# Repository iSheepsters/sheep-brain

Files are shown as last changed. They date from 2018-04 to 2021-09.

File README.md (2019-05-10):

# Config file

| Value | Description |
| --- | --- |
| sheepNum | the number for the sheep voices |
| stable sensor value | if non-zero, use as stable value
| privates enabled | if non-zero, private sensor is enabled
| R rated | if non-zero, R rated sounds enabled
| default volume | 0 - 63, 63 is maximum, 0 is silent, 50 is a typical loud volume
| min sound delay | minimum delay in seconds between sound clips (suggest 12)
| max sound delay | maximum delay in seconds between sound clips (suggest 25)
| time zone offset | difference from ET
| # time periods | the number of lines each containing the following fields 
| start duration volume | start is the starting o’clock in EST (0-23) for a volume reduction, duration is the number of hours, volume in that window

For example, the following config file
```
1
0
0
0
48
12
25
0
1
22 10 40
```

Specifies the following:
* Sheep 1
* privates not enabled
* R-rated sounds not enabled
* default volume of 48
* delay until next sound of 1/2 duration of previous clip plus 12-25 seconds
* no time zone offset (use EST)
* 1 time period offset
 * If time is between 10pm and 8am, use a volume of 40

# Libraries used

| Library | Version | Notes |
| --- | --- |  --- |
|Adafruit Sleepydog
|Wire
|TimeLib
|Adafruit\_GPS
|RH\_RF95
|Adafruit\_VS1053 | Custom | Modified to use SdFat
|SdFat
| Adafruit\_MPR121 | 

# Hardware

| Module | I2C  | Serial | SPI |  Notes |
| --- | --- | --- | --- | --- |
| [Feather M0/LoRa][1] | |  | 
| [Music Maker FeatherWing][2] |  | | yes | Both audio codec and SD card; SD select = 5
| [GPS Featherwing][3] | | yes | |
| [Capacitive Touch Sensor][4] | 0x5A | | | 
| [20W amplifier][5] | 0x4B | | | |
| Teensy 3.5 | 0x44 | | | 

[1]:	https://learn.adafruit.com/adafruit-feather-m0-radio-with-lora-radio-module/downloads
[2]:	https://learn.adafruit.com/adafruit-music-maker-featherwing/
[3]:	https://learn.adafruit.com/adafruit-ultimate-gps-featherwing
[4]:	https://learn.adafruit.com/adafruit-mpr121-12-key-capacitive-touch-sensor-breakout-tutorial
[5]:	https://learn.adafruit.com/adafruit-20w-stereo-audio-amplifier-class-d-max9744

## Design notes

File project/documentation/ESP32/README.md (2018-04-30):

GitHub:

Heltec Board: https://github.com/Heltec-Aaron-Lee/WiFi_Kit_series

Install (OSX): https://github.com/Heltec-Aaron-Lee/WiFi_Kit_series/blob/master/InstallGuide/mac.md

Product Page:
https://www.amazon.com/gp/product/B076MSLFC9/

Wiki:

Documentation:

ESP32: https://www.espressif.com/en/products/hardware/esp32/resources

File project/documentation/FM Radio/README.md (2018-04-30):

https://www.sparkfun.com/datasheets/Wireless/General/TEA5767.pdf
Best option? https://www.amazon.com/Gikfun-TEA5767-Stereo-Module-Arduino/dp/B00RECZ142
https://www.hackster.io/nickthegreek82/arduino-tea5767-fm-radio-receiver-543480

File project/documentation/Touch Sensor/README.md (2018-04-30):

# GitHub:

# Product Page:
https://www.adafruit.com/product/1982

# Wiki:

# Documentation:
Tutorial: https://learn.adafruit.com/adafruit-mpr121-12-key-capacitive-touch-sensor-breakout-tutorial
General intro to touch: https://learn.adafruit.com/adafruit-capacitive-touch-sensor-breakouts?embeds=allow

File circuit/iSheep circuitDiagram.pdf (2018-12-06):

Head LEDs | Left side LEDs | Right side LEDs

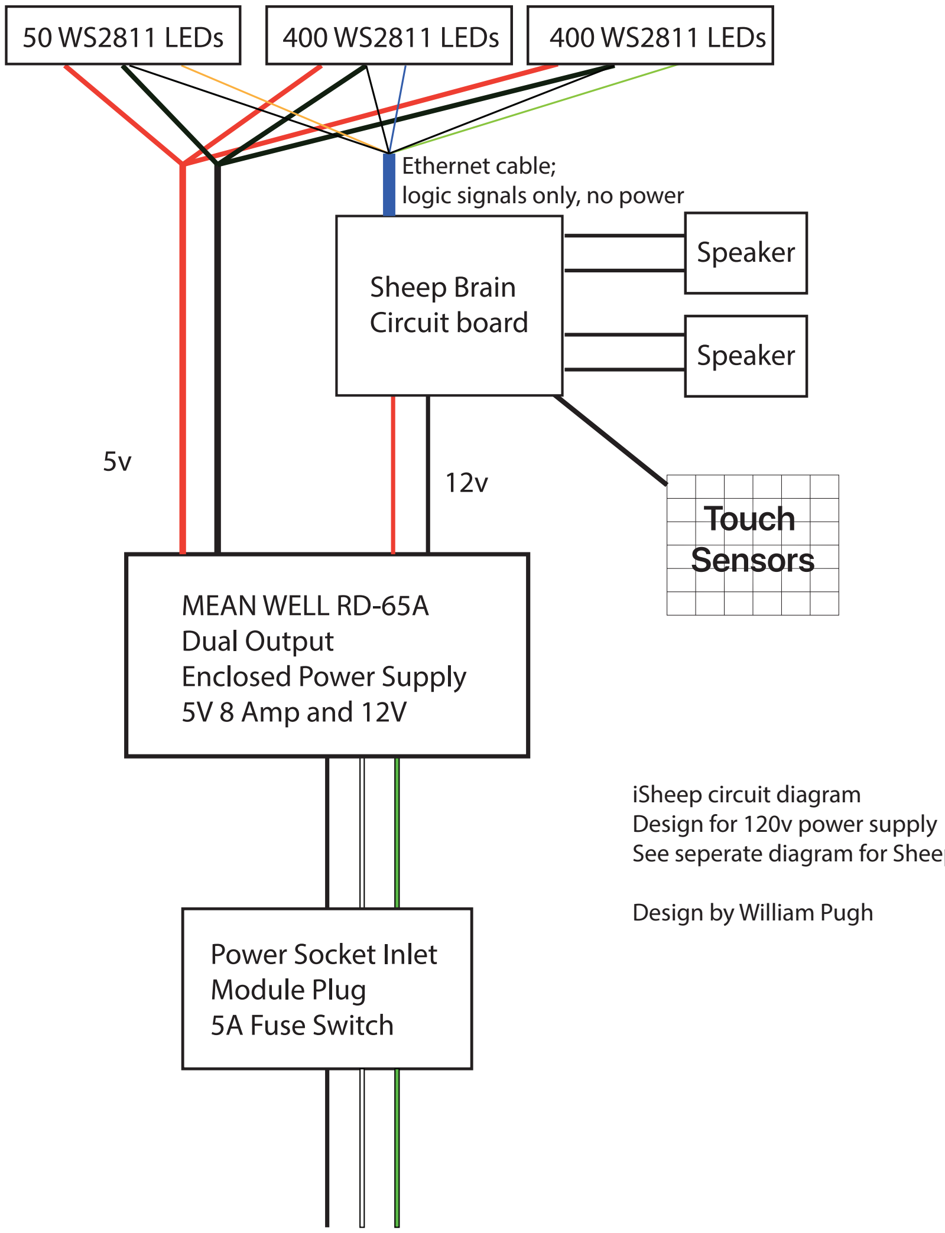
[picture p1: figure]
Power Socket Inlet Module Plug 5A Fuse Switch; MEAN WELL RD-65A Dual Output Enclosed Power Supply 5V 8 Amp and 12V; Sheep Brain Circuit board; Speaker; Touch Sensors; Ethernet cable; logic signals only, no power; iSheep circuit diagram Design for 120v power supply; Design by William Pugh

50 WS2811 LEDs | 400 WS2811 LEDs | 400 WS2811 LEDs

See seperate diagram for Sheep Brain circuit board

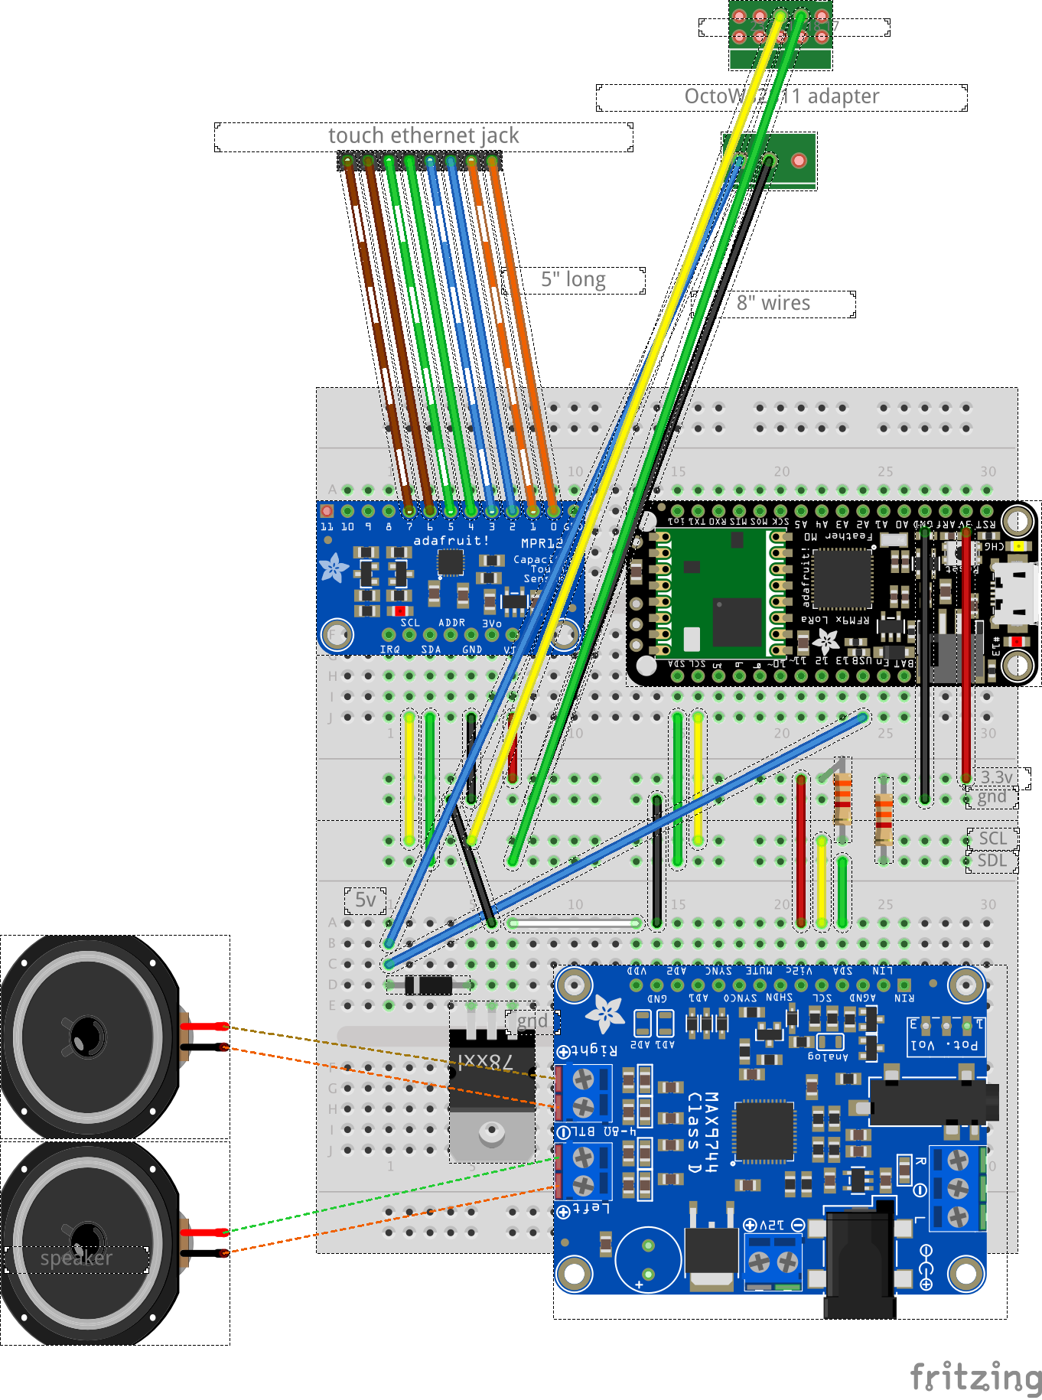
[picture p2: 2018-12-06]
circuit/sheepBrainCircuitNoBattery_bb.png

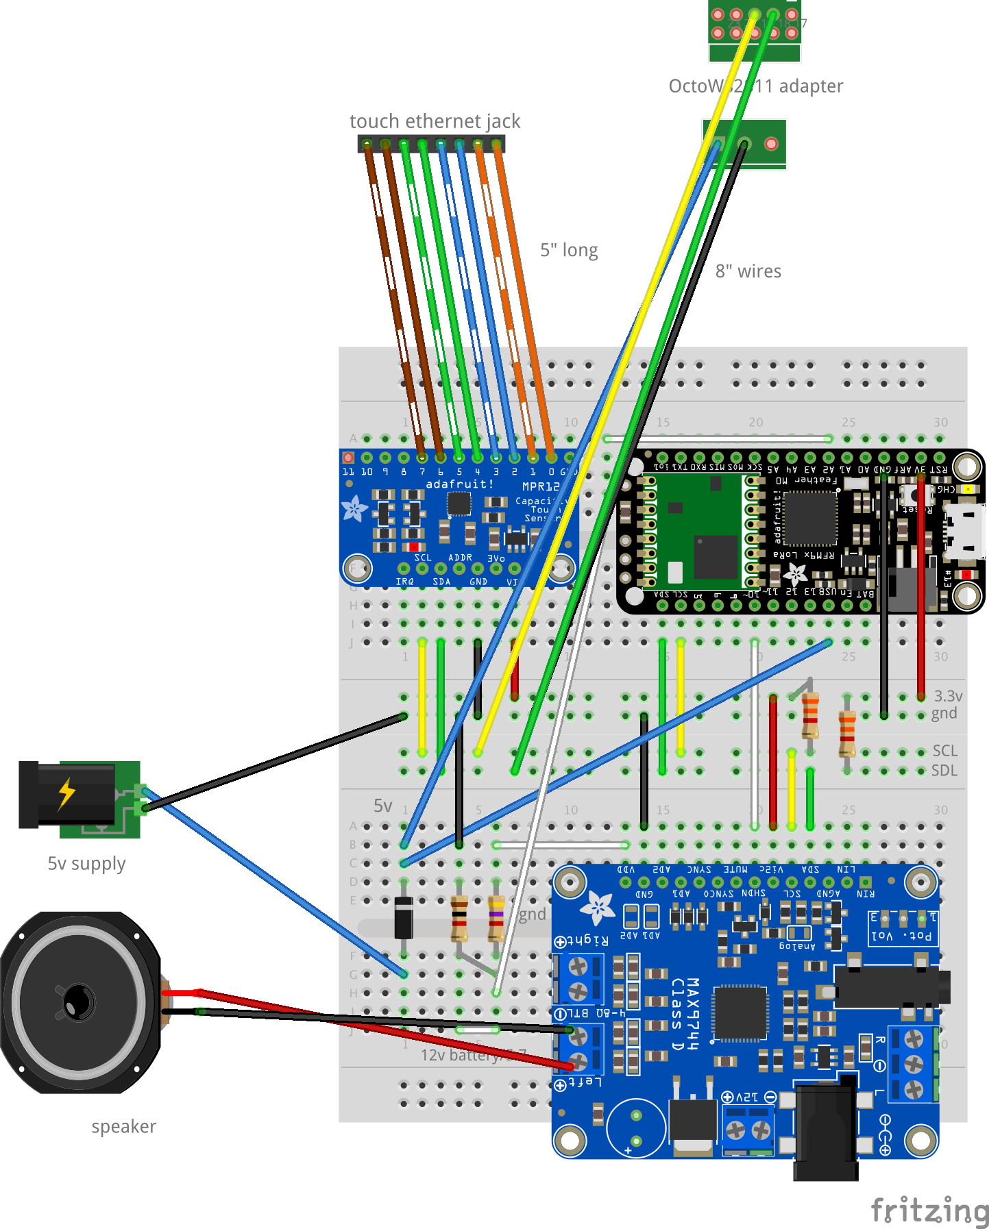
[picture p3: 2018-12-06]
circuit/sheepBrainCircuit_bb.png

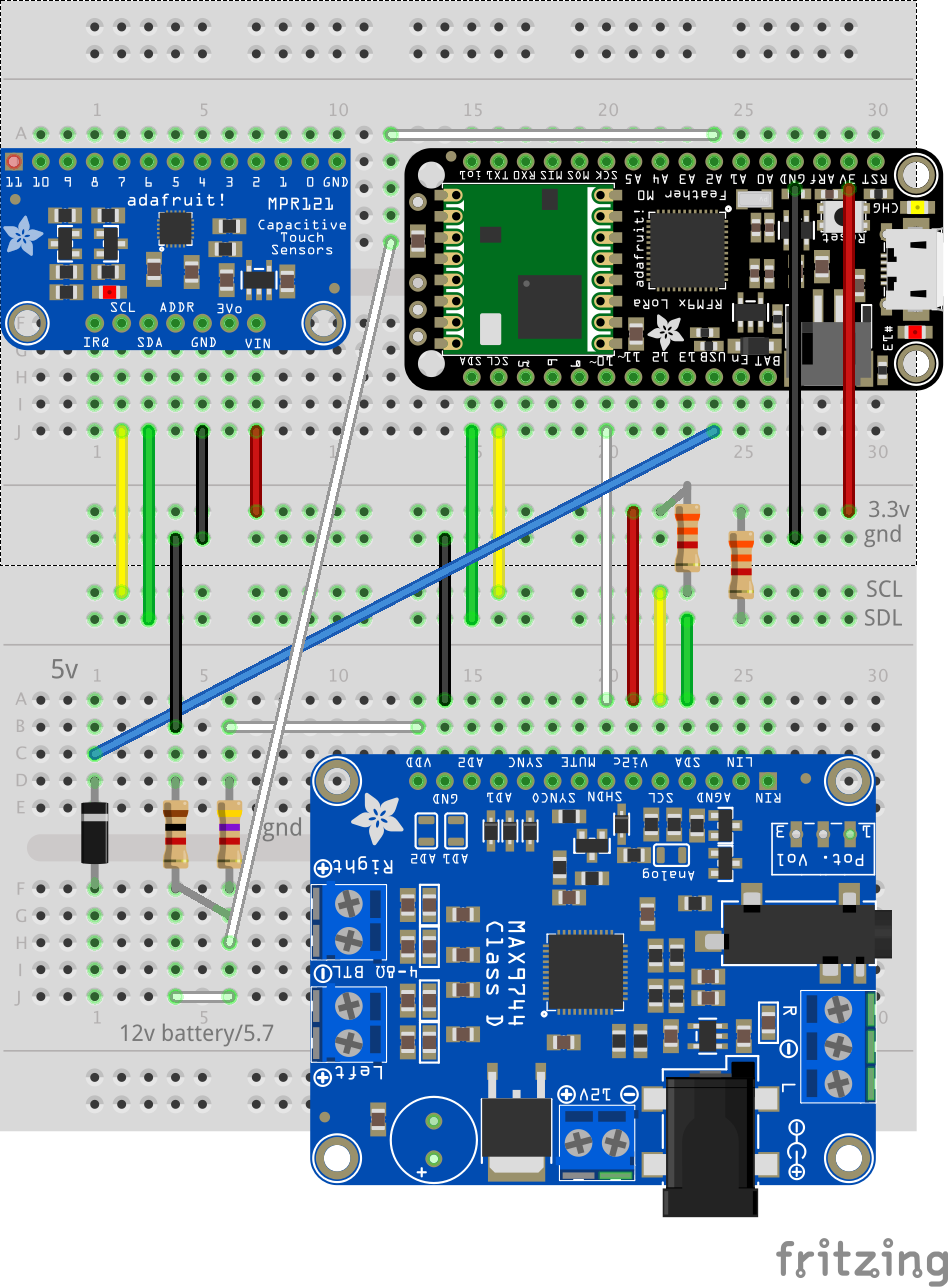
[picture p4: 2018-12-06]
circuit/sheepBrainCircuitPortion_bb.png

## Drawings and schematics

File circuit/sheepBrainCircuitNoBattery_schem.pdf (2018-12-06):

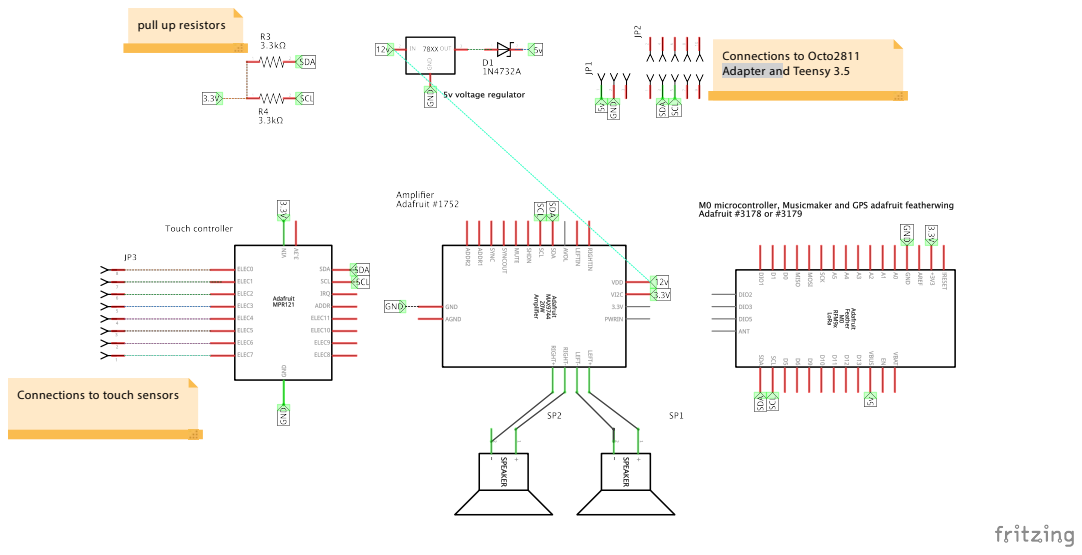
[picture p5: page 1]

pull up resistors

Connections to Octo2811
Adapter and Teensy 3.5
Adapter an

Connections to touch sensors

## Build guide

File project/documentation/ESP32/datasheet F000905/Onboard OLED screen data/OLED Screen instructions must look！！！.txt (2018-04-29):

1. 0.96 inch is 128 * 64 dot matrix;
2. 0.91 inch is 128 * 32 dot matrix;
3. Both screens use SSD1306 driver chip, use IIC communication, OLED screen and ESP8266 or ESP32 chip OLED connection diagram, please refer to Diagram;
4. The display part of the circuit is not added to the power reset circuit, initialization before the need for IO to reset it, or may not be able to initialize.

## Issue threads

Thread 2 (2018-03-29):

Investigate audio module

objectiveSee, 2018-03-29:
Purchase and assemble circuit to play audio from ESP32 or Arduino using a MP3 module. Determine if this will satisfy our project needs. They can be purchased on Amazon for $5-$10

https://www.dfrobot.com/product-1121.html

Documentation: https://www.dfrobot.com/wiki/index.php/DFPlayer_Mini_SKU:DFR0299

objectiveSee, 2018-04-16:
Some parts we can try:

**Amplifier:**

I don't know what power or other requirements we will demand for amp.

https://www.amazon.com/5V-12V-Amplifier-Module-Arduino-EK1236/dp/B01FDD3FYQ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

Documentation: https://www.adafruit.com/product/987

or

https://www.amazon.com/Audio-Development-Tools-Stereo-Amplifier/dp/B00N42NP6W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

**MP3 Module:**

https://www.amazon.com/Longruner-DFPlayer-Player-Arduino-LK01/dp/B01MXOFAE4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

**Speaker**
IDK anything this... but some cheap-o one should do for our preliminary hacking.

https://www.amazon.com/Adafruit-Stereo-Enclosed-Speaker-Set/dp/B00QSJ1HA4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

jslabovitz, 2018-04-18:
I'm feeling that we should use weatherproof speakers. The cones are plastic instead of paper, and other parts are generally better sealed and protected.

Here's one that's reasonably priced @ $12.50/pair == $6.25 each:

https://www.parts-express.com/pyle-plmr41w-4-dual-cone-waterproof-speaker-pair-white--267-7024

jslabovitz, 2018-04-18:
It appears that the MP3 module can *not* write to the SD card. Nor can the data on the card be accessed in any way other than being a folder/file reference for the player module.

This is probably for the best, as SD cards are easily corrupted in the field. Treating the audio SD card as read-only (from the sheep's point of view) is probably best for reliability. (Though it would still be a good idea to have a pile of SD duplicates while at BRC for easy swap-out.)

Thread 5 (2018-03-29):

Investigate touch sensors

objectiveSee, 2018-03-29:
Purchase and install touch sensors as they will be on the sheep. Connect to esp32/arduino and determine whether we can use them to detect touches.

billpugh, 2018-04-03:
How many touch locations do we need per sheep? This circuit gives 12 capacitive touch sensors and costs $8. https://www.adafruit.com/product/1982

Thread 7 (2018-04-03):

Storyboard how the sheep "reactions" work

objectiveSee, 2018-04-03:
Work with Bardia to write some technical storyboards on how the sheep behavior translates to lights, sounds, and other actions.

objectiveSee, 2018-04-16:
I took a stab at writing up a technical spec for the `emotion` and `behavior` code. Feedback is appreciated!!

## **Emotion**

Filenames: `emotion.h`/`emotion.cpp`

A code module (in C++ called a “class") named `emotion` that handles the following responsibilities:

- Keep track of the current emotional state (e.g. happy, sad, lonely, philosophical)
- Responsible for changing emotional state based on multiple inputs
- Keep track of the touch sensors (in their own class, `touch.h`) and be informed of updates to the touch sensors state
- Monitor for changes in inputs (see “Emotional Inputs” below)

Emotional Inputs:
- elapsed time since last emotional change (e.g. it’s been 5 minutes since I’ve been touched, I was happy and now I’m lonely)
- time of day (e.g. howl at sunset)
- “flock” wireless message - messages from other sheep about their state
- “flock state” (e.g. the number of sheep nearby)
- “shepherd" wireless messages - WiFi commands from the base station, this is mostly useful during debugging and development but could also let the shepherds have some extra POWER
- GPS state - Whether the sheep is located within range of the corral, near the corral, very far, etc.

DISCUSS:
1. Should this class be called something else, like `limbic_system`, so that `emotion` can be used for a class that defines the properties of each emotion (e.g. the `happy` emotion would have different properties than the `sad` emotion)

## **Behavior**

Filenames: `behavior.h`/`behavior.m`

A class called `behavior` responsible for taking action and making decisions as a Sheep. Features:

- Monitor the `emotion` for state changes
- Deciding which actions should happen (see “Actions” below)
- Keep track of recently taken actions (so we don’t play audio clips on top of each other)

Actions:
- Tell the lights (`light` class TBD) to change state (DISCUSS: the light class could also do this directly depending on the relationship between `light`, `emotion` and `behavior` classes. However, I think the paradigm of `behavior` acting as the main controller for actions has merit).
- Decide whether the audio module should play a sound clip (mp3)
- Acknowledge a state change. If the sheep was horny and you touch his junk, he’ll change to “happy” state, but should also respond knowing that the state change they wanted was satisfied.
- Shutdown all actions when low-power mode is entered

Naive concept for Behavior algorithm:

Audio:
- When the state changes, play a random audio clip from the folder of clips for that state.
- Each emotional state has an `interval` property specifying a time in seconds. Another audio clip is played if its been more than the `interval` since the last audio was played. We could also add some randomness to this (e.g. interval +/- a random number)

Lights:
- Lights select an LED pattern based on the emotional state.

Advanced concepts for Behavior algorithm (aka. things we *might* do):
- Create a “request” such as “please ask for consent” or “stop riding me”. DISCUSS: This could be skipped if we tie request in with certain emotional states. For example, if you’re annoyed, there is an implicit request to stop riding or molesting you.
- Have a “map” of how to act based on previous and current emotion. If we go from “annoyed”, “sad” or “lonely” to “happy”, then we could have a specific reaction such as audio saying “thank you”. DISCUSS: I’m not 100% sure what this should be. Does which state you came from matter, or should your behavior be based solely on the current state?

ebardia, 2018-04-18:
I think emotional state plus the inputs is enough to go to the next emotional state; No need for knowing the map of what the past emotional state was;  But there will be lots and lots of emotional states; Each emotional state can go up and down the "consent" path depending on the input.  Ultimately we want the sheep to give consent for rides (unlimited time interval as long as other limits of flock state and such aren't crossed) and provide enough instructions in the form of sound clips for the emotional state to go down the consent path.  If the rider does something different than instructed, then the sheep goes up the consent path to a different emotional state that has not been in so for.  (eg. Everything was OK, then the rider deviated from the instruction.)  This doesn't take the state up to previous, but to a new state.

jslabovitz, 2018-04-18:
This is a side/implementation issue, but it seems like the lighting could work in a very similar way as the audio. Might be useful to abstract these responses: a trigger causes an action (LEDs: play sequence of RGB values; audio: play specific file), which has a duration, after which another trigger signifies the action is finished, and another action taken.

ebardia, 2018-04-18:
I think we are on the same page.  Each trigger (emotional state change)
causes a new sound file and a new led pattern.

On Wed, Apr 18, 2018 at 9:55 AM John Labovitz <notifications@github.com>
wrote:

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
--
Bardia Saeedi
Lights for dark spaces and darker times
www.pixelucy.com

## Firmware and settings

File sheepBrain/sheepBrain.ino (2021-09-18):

#include <Adafruit_SleepyDog.h>
// #include <Adafruit_ASFcore.h>
//#include <MemoryFree.h>
const boolean WAIT_FOR_SERIAL = false;
#include <Adafruit_ZeroTimer.h>

#include <Adafruit_ZeroDMA.h>
#include <Wire.h>
#include <SdFat.h>
#include "util.h"
#include "sound.h"
#include "printf.h"
#include "touchSensors.h"
#include "soundFile.h"
#include "comm.h"
#include "state.h"
#include "time.h"


#include "logging.h"
#include "scheduler.h"




extern  void checkForCommand();

// If the initial sheepNumber is anything other than 15, it will be
// rewritten by what is on the SD card. 15 is a placeholder, there
// shouldn't be a real sheep with that number.
// sheepNumber 14 is for shepherd

const int WATCHDOG_TIMEOUT = 10000;
uint8_t sheepNumber = 15;
SheepInfo infoOnSheep[NUMBER_OF_SHEEP];

SheepInfo & getSheep(int s) {
  if (s < 1 || s > NUMBER_OF_SHEEP) {
    myprintf(Serial, "invalid request for sheep %d\n", s);
    return infoOnSheep[0];
  }
  return infoOnSheep[s - 1];
}


SoundCollection generalSounds(0);
SoundCollection boredSounds(0);
SoundCollection firstTouchSounds(2);
SoundCollection ridingSounds(2);
SoundCollection readyToRideSounds(2);

SoundCollection attentiveSounds(1);
SoundCollection notInTheMoodSounds(1);
SoundCollection violatedSounds(1);
SoundCollection baaSounds(0);


// not a state
SoundCollection endOfRideSounds(3);
SoundCollection inappropriateTouchSounds(4);
SoundCollection seperatedSounds(1);
SoundCollection changeSounds(0);


unsigned long setupFinished = 0;
uint16_t minutesUptime() {
  return ( millis() - setupFinished) / 1000 / 60;
}

unsigned long nextTestDistress = 0xffffffff; // disable test distreess

volatile unsigned long lastInterrupt = 0;
volatile  long longestInterval = 0;
volatile unsigned int maxAvail = 0;
volatile int maxInterruptTime = 0;

void checkForNextAmbientSound();


unsigned long nextActivityReport = 0;
volatile uint16_t periodicTicks = 0;
// execute this code at 20Hz

void periodicTask(void) {
  periodicTicks++;
  unsigned long start = micros();
  if (false) {
    unsigned long ms = millis();
    if (currentActivityStartedAt + 500 < ms && nextActivityReport < ms) {
      myprintf(Serial, "activity %d.%d, started %dms ago\n",
               currentActivity, currentSubActivity,
               ms - currentActivityStartedAt);
      nextActivityReport = ms + 1000;
    }
  }
  
  if (musicPlayerReady && musicPlayer.playingMusic)
    musicPlayer.feedBuffer();
  unsigned long end = micros();
  long diff = end - start;
  if (maxInterruptTime < diff)
    maxInterruptTime = diff;
}


// timer tester
Adafruit_ZeroTimer zerotimer = Adafruit_ZeroTimer(4);

void setupPeriodTask() {
  Serial.println("setup periodic task");
  int freq = 20;
  uint8_t  divider = 64;
  tc_clock_prescaler prescaler = TC_CLOCK_PRESCALER_DIV64;
  uint16_t   compare = (48000000 / 64) / freq;
  zerotimer.enable(false);
  zerotimer.configure(prescaler,       // prescaler
                      TC_COUNTER_SIZE_16BIT,       // bit width of timer/counter
                      TC_WAVE_GENERATION_MATCH_PWM // frequency or PWM mode
                     );

  zerotimer.setCompare(0, compare);
  zerotimer.setCallback(true, TC_CALLBACK_CC_CHANNEL0, periodicTask);
  zerotimer.enable(true);
}

void testSwapLeftRight(uint8_t touched) {
  myprintf(Serial, "testSwapLeftRight %02x -> %02x\n",
           touched, swapLeftRightSensors(touched));
}

void setup() {
  // disable the radio module until we are ready for it
  pinMode(8, INPUT_PULLUP);
  // disable VS1053 until we are ready for it
  pinMode(6, INPUT_PULLUP);
  // disable SdCard until we are ready for it
  pinMode(5, INPUT_PULLUP);

  delay(300);
  memset(&infoOnSheep, 0, sizeof (infoOnSheep));
  pinMode(LED_BUILTIN, OUTPUT);

  delay(100);
  Serial.begin(115200);
  for (int i = 0; i < 4; i++) {
    Serial.println(i);
    delay(100);
  }
  int countdownMS = Watchdog.enable(WATCHDOG_TIMEOUT);
  myprintf(Serial, "Watchdog set, %d ms timeout\n", countdownMS);

  int clearBus = I2C_ClearBus();
  if (clearBus != 0)
    while (true) {
      Serial.println(F("I2C bus error. Could not clear"));
      if (clearBus == 1) {
        Serial.println(F("SCL clock line held low"));
      } else if (clearBus == 2) {
        Serial.println(F("SCL clock line held low by slave clock stretch"));
      } else if (clearBus == 3) {
        Serial.println(F("SDA data line held low"));
      } else
        Serial.println(F("Unknown return value from I2C_ClearBus"));
      delay(500);
    }

  Wire.begin();

  if (WAIT_FOR_SERIAL) while (!Serial && millis() < 8000) {
      digitalWrite(LED_BUILTIN, HIGH);   // turn the LED on (HIGH is the voltage level)
      setupDelay(200);                     // wait for a second
      digitalWrite(LED_BUILTIN, LOW);    // turn the LED off by making the voltage LOW
      setupDelay(200);
    }


  randomSeed(analogRead(0));
  myprintf(Serial, "\n\n\n\nCompiled %s, %s\n", F(__DATE__), F(__TIME__));

  countdownMS = Watchdog.enable(WATCHDOG_TIMEOUT);
  myprintf(Serial, "Watchdog set, %d ms timeout\n", countdownMS);

  // myprintf(Serial, "Free memory = %d\n", freeMemory());



  if (useSlave) {
    Serial.println("Setting up comm");
    setupComm();
    sendBoot();
  } else
    Serial.println("Skipping comm");

 
  Watchdog.reset();
  if (useSound) {
    Serial.println("Setting up sound");
    setupSound();
    Serial.println("Sound setup");
  } else
    Serial.println("Skipping sound");

    Serial.println("Setting up time");
    setupTime();





  Watchdog.reset();
  if (!setupSD()) {
    Serial.println("setupSD failed");
    Serial.println("huh");
    logDistress("SD card not found");
    while (true) {
      digitalWrite(LED_BUILTIN, HIGH);   // turn the LED on (HIGH is the voltage level)
      setupDelay(1000);                     // wait for a second
      digitalWrite(LED_BUILTIN, LOW);    // turn the LED off by making the voltage LOW
      setupDelay(1000);
      Serial.print("setupSD failed, time: ");
      Serial.println(millis());
    }
  }
  Watchdog.reset();
  // myprintf(Serial, "Free memory = %d\n", freeMemory());
  int s = 1;
  File configFile = SD.open("config.txt");
  if (!configFile) {

    logDistress("no config.txt file");

  } else {
    Watchdog.reset();
    s = configFile.parseInt();
    myprintf(Serial, "config file contains %d\n", s);

    int v = configFile.parseInt();
    if (v != 0) {
      STABLE_VALUE = v;
      myprintf(Serial, "stable sensor value set to %d\n", v);
    } else {
      myprintf(Serial, "stable sensor value not set\n", v);
    }
    v = configFile.parseInt();
    if (v != 0) {
      privatesEnabled = true;
      Serial.println("Privates enabled");
    } else Serial.println("Privates disabled");
    v = configFile.parseInt();
    if (v != 0) {
      allowRrated = true;
      Serial.println("R rated sounds enabled");
    } else
      Serial.println("R rated sounds disabled");
    v = configFile.parseInt();

    if (v > 0 && v <= 63) {
      thevol = v;
      myprintf(Serial, "default volume set to %d\n", v);
    } else
      myprintf(Serial, "default volume not set, using %d\n", thevol);

    v = configFile.parseInt();
    if (v != 0) {
      myprintf(Serial, "min time to next sound: %d secs\n", v);

      msToNextSoundMin = v * 1000;
    }
    v = configFile.parseInt();
    if (v != 0) {
      myprintf(Serial, "max time to next sound: %d secs\n", v);
      msToNextSoundMax = v * 1000;
    }

    configFile.close();
  }
  Watchdog.reset();
  if (s < 0 || s >= NUMBER_OF_SHEEP)
    s = 1;

  if (sheepNumber == PLACEHOLDER_SHEEP) {
    sheepNumber = s;
    myprintf(Serial, "I am sheep %d\n", sheepNumber);

  } else {

    myprintf(Serial,
             "Sheep number hard coded as %d, ignoring value of %d on sd card\n",
             sheepNumber, s);
  }

  setupLogging();
  myprintf(logFile, "Start of log for sheep %d\n", sheepNumber);
  Watchdog.reset();
  if (useSound) {

   // myprintf(Serial, "Free memory = %d\n", freeMemory());
    Serial.println("Sound set up, examining sound files");

    loadPerSheepSounds();

    if (minutesPerSheep > 0)
      changeSounds.loadCommon("change");
    baaSounds.loadCommon("baa");
    baaSounds.playSound(millis(), false);
   // myprintf(Serial, "Free memory = %d\n", freeMemory());
  } else
    Serial.println("Skipping sound");

  if (useTouch) {
    Serial.println("Setting up touch");
    setupTouch();
    Serial.println("touch set up");
  } else
    Serial.println("Skipping touch");

  addScheduledActivity(10000, generateReport, "report");
  if (useSound && playSound)
    addScheduledActivity(500, checkForNextAmbientSound, "ambient sound");
  setupState();
  if (useCommands) {
    addScheduledActivity(500, checkForCommand, "commands");
  }
  logTouchConfiguration();
  updateLog(setupFinished);
  
  


  if (useSlave) {
    Serial.println("Getting last boot from teensy");
    logBoot();
  }

  Serial.println();
  sendActivity(101);
  setupFinished = millis();
  myprintf(Serial, " %dms set up time\n", setupFinished);
  myprintf(logFile, "sheep %d ready, ", sheepNumber);
  myprintf(logFile, "Compiled %s, %s\n", F(__DATE__), F(__TIME__));
  listScheduledActivities();

  // myprintf(Serial, "  Free memory = %d\n", freeMemory());
  myprintf(Serial, "setup complete, sheep %d\n",
           sheepNumber);
  myprintf(Serial, "Compiled %s, %s\n", F(__DATE__), F(__TIME__));
  randomSeed(analogRead(0));
  startSchedule();

}


const boolean TRACE = false;

unsigned long lastReport = 0;

void generateReport() {
  if (plotTouch) return;
  unsigned long now = millis();
  myprintf(Serial, "%d/%d State %s, %f volts,  %d minutes uptime, %2d:%02d:%02d\n",
           sheepNumber, now, currentSheepState->name,
           batteryVoltage(),  minutesUptime(), 
           hour(), minute(), second());
  myprintf(Serial, "  untouch duration %d\n", untouchDuration());
  if (!isActive()) {
     myprintf(Serial, "not active");
  }

  myprintf(Serial, "  local time %2d:%02d:%02d\n",

           adjustedHour(), minute(), second() );
  myprintf(Serial, "  %dms interrupt interval, %dus max interrupt time, %d max avail\n",
           longestInterval, maxInterruptTime, maxAvail);
  // myprintf(Serial, "  Free memory = %d\n", freeMemory());
  myprintf(Serial, "  periodic ticks: %d\n", periodicTicks);

  if (thevol != INITIAL_AMP_VOL)
    myprintf(Serial, "  amplifier volume %d\n", thevol);
  if (currentSoundFile != NULL)
    myprintf(Serial, "  playing %s/%s\n", currentSoundFile->collection->name,
             currentSoundFile -> name);
  else if (musicPlayer.playingMusic)
    Serial.println("  Playing unknown sound");
  else {
    myprintf(Serial, "next ambient sound in %d ms\n", nextAmbientSound - now);
    myprintf(Serial, "next baa in %d ms\n", nextBaa - now);
  }

  

 

  longestInterval = 0;
  maxAvail = 0;
  maxInterruptTime = 0;
 
  lastReport = now;
  sendSubActivity(10);
  if (useLog) {
    if (TRACE)
      Serial.println("Updating log");
    updateLog(now);
    if (TRACE)
      Serial.println("Log updated");
  }
}




unsigned long lastLoop = 0;


const uint16_t REPORT_INTERVAL = 10000;

void considerReboot() {
  
}
void loop() {
   periodicTask();
  considerReboot();
  Watchdog.reset();
  interrupts();
  totalYield = 0;
  SheepInfo & me = getSheep();
  me.time = now();
  me.uptimeMinutes = minutesUptime();
  me.batteryVoltageRaw = batteryVoltageRaw();
  me.errorCodes = 0;
  unsigned long now = millis();
  unsigned long nowMicros = micros();

  if ((now / 500) % 2 == 1)
    digitalWrite(LED_BUILTIN, HIGH);
  else
    digitalWrite(LED_BUILTIN, LOW);


  


  if (totalYield > 20 && printInfo()) {
    myprintf(Serial, "total yield %dms\n", totalYield);
  }

  runScheduledActivities();

  yield(10);
}

const int DELAY_BETWEEN_SOUNDS = 5000;
void checkForNextAmbientSound() {
  unsigned long now = millis();
  if (!useSound || !playSound)
    return;

  if (musicPlayer.playingMusic || soundPlayedRecently(now)) {
    return;
  }
  if (now > nextAmbientSound) {
    if (TRACE) Serial.println("play ambient sound");
   
    if (currentSheepState -> playAmbientSound(now)) {
      unsigned long delay = DELAY_BETWEEN_SOUNDS;
      if (currentSoundFile -> duration > 0 && currentSoundFile -> duration / 2 < delay)
        delay = currentSoundFile -> duration / 2 ;
      delay = (delay + random(msToNextSoundMin, msToNextSoundMax)) ;
      if (printInfo())
        myprintf(Serial, "Started playing ambient sound, next in %dms\n", delay);
      nextAmbientSound = now + delay;
      return;
    } else  if (baaSounds.playSound(now, true)) {

      if (printInfo()) myprintf(Serial, "No ambient sound available, baa-ing\n");

      unsigned long delay = random(msToNextSoundMin, msToNextSoundMax) ;
      nextAmbientSound = now + delay;
      nextBaa = now + delay + DELAY_BETWEEN_SOUNDS / 2;
    } else {
      myprintf(Serial, "No ambient or baa sound available\n");
      nextAmbientSound = now + DELAY_BETWEEN_SOUNDS / 4;
    }
  }
  if (now > nextBaa && nextBaa + 4000 < nextAmbientSound) {
    if (TRACE) Serial.println("play baa sound");
    if (baaSounds.playSound(now, true)) {
      unsigned long delay = random(msToNextSoundMin, msToNextSoundMax) ;
      if (printInfo()) myprintf(Serial, "Started playing baa sound, next in %dms\n", delay);
      nextBaa = now + delay;
      return;
    } else
      nextBaa = now + 3000 + random(1, 5000);
  }

}

unsigned long nextCommandCheck = 0;
void checkForCommand() {
  unsigned long now = millis();
  if (nextCommandCheck > now)
    return;
  nextCommandCheck = now + 200;
  if (Serial && Serial.available()) {
    char c = Serial.read();
    if (c != '\n') {
      if (printInfo()) {
      Serial.println();
      Serial.print("Got " );
      Serial.println(c);
      }
      switch (c) {

        case 'a':
          playFile("baa%d.mp3", 1 + random(8));
          break;
        case 'w':
          attentiveSounds.playSound(now, false);
          break;
        case 'r':
          ridingSounds.playSound(now, false);
          break;
        case 'b':
          boredSounds.playSound(now, false);
          break;
        case 'd':
          Serial.println(musicPlayer.startPlayingFile("drumbone.mp3"));
          break;
        case 's':
          musicPlayer.stopPlaying();
          break;
        case 't':
          dumpConfiguration();
          dumpTouchData();
          debugTouch = !debugTouch;
          break;
          
         case '0':
         case '1':
         case '2':
         case '3':
         case '4':
         case '5':
         case '6':
         if (plotTouch) {
          sensorToPlot = c - '0';
         }
         break;

        case 'p':
          dumpConfiguration();
          dumpTouchData();
          plotTouch = !plotTouch;
          if (plotTouch) {
            sensorToPlot = numTouchSensors;
          }
          break;
      }
    }
  }
}

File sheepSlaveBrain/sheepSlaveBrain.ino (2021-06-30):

#include <Adafruit_SleepyDog.h>

#include<FastLED.h>

#define STANDARD_SHEEP

#include "all.h"
#include "comm.h"
#include "hsv2rgb.h"
#include "animations.h"
#include "overlays.h"
#include <TimeLib.h>

const int led = 13;
const uint8_t NUM_STRIPS  = 8;

const  uint8_t HEAD_STRIP = 0;
const  uint8_t LEFT_STRIP = 1;
const  uint8_t RIGHT_STRIP = 2;

CRGB unusedLED;

#ifdef STANDARD_SHEEP

const uint16_t NUM_LEDS_PER_STRIP  = 400;
const enum EOrder LED_COLOR_ORDER = RGB;
CRGB leds[NUM_STRIPS * NUM_LEDS_PER_STRIP];

CRGB & getSheepLEDFor(uint8_t x, uint8_t y) {
  if (x >= GRID_WIDTH || y >= GRID_HEIGHT)
    return unusedLED;
  // 0 <= x < GRID_WIDTH
  // 0 <= y < GRID_HEIGHT
  uint8_t strip;
  uint16_t pos;
  if (x >= HALF_GRID_WIDTH) {
    strip = 2;
    pos = (x - HALF_GRID_WIDTH) * GRID_HEIGHT;

  } else {
    strip = 1;
    pos = (HALF_GRID_WIDTH - 1 - x) * GRID_HEIGHT;
  }
  if ((x + strip) % 2 == 0)
    pos += y;
  else
    pos += (GRID_HEIGHT - 1 - y);

  return leds[strip * NUM_LEDS_PER_STRIP + pos];
}

const uint8_t BRIGHTNESS_NORMAL = 230;
const uint8_t BRIGHTNESS_BORED = 160;

#else
const uint16_t NUM_LEDS_PER_STRIP  = 256;
const enum EOrder LED_COLOR_ORDER = GRB;
CRGB leds[NUM_STRIPS * NUM_LEDS_PER_STRIP];

CRGB & getSheepLEDFor(uint8_t x, uint8_t y) {
  uint8_t strip = 1 + y / 8;
  if (strip == 4)
    return unusedLED;
  uint8_t pos = 8 * x;
  y = y % 8;
  if (x % 2 == 0)
    pos += y;
  else
    pos += 7 - y;
  return leds[strip * NUM_LEDS_PER_STRIP + pos];
}

const uint8_t BRIGHTNESS_NORMAL = 80;
const uint8_t BRIGHTNESS_BORED = 40;

#endif


void copyLEDs() {
  uint16_t halfWay = 4 * NUM_LEDS_PER_STRIP;
  for (int i = 0; i < halfWay; i++) {
    leds[i + halfWay] =  leds[i];
  }
}


void setup() {
  pinMode(led, OUTPUT);
  digitalWrite(led, LOW);
  LEDS.addLeds<WS2811_PORTD, NUM_STRIPS, LED_COLOR_ORDER>(leds, NUM_LEDS_PER_STRIP);
  LEDS.setBrightness(BRIGHTNESS_BORED);
  LEDS.clear();
  setLEDsToBlack();
  LEDS.show();
  LEDS.setCorrection(TypicalLEDStrip);

  digitalWrite(led, HIGH);
  Serial.begin(115200);
  Serial.println("Starting sheep LED brain");
  
  LEDS.show();
  if (true) {
    int countdownMS = Watchdog.enable(14000);
    Serial.print("Enabled the watchdog with max countdown of ");
    Serial.print(countdownMS, DEC);
    Serial.println(" milliseconds!");
    Serial.println();
  }
  for (int i = 0; i < 5; i++) {
    digitalWrite(led, HIGH);   // turn the LED on (HIGH is the voltage level)
    delay(50);               // wait for a second
    digitalWrite(led, LOW);    // turn the LED off by making the voltage LOW
    delay(50);
    Serial.println(i);
  }
  LEDS.show();
  setupComm();
  Serial.println("comm set up");

  setupAnimations();
  Serial.println("animations set up");



  for (int i = 0; !receivedMsg && i < 100; i++) {
    digitalWrite(led, HIGH);   // turn the LED on (HIGH is the voltage level)
    delay(25);               // wait for a second
    digitalWrite(led, LOW);    // turn the LED off by making the voltage LOW
    delay(25);
    Serial.println(i);
    LEDS.show();
  }



  Serial.println("setup complete");
  myprintf( "\n\n\n\nCompiled %s, %s\n", F(__DATE__), F(__TIME__));


}

unsigned long nextUpdate = 0;

int counter = 0;

boolean isDaytime() {
  if (!receivedMsg)
    return false;
  int h = hour();
  return h >= 7 && h <= 18;
}


void setLEDsToBlack() {
  for (int j = 0; j < NUM_STRIPS * NUM_LEDS_PER_STRIP; j++)
    leds[j] = CRGB::Black;
}

void loop() {
  Watchdog.reset();
  unsigned long now = millis();

  State currState = commData.state;
  digitalWrite(led, (now / 1000) % 2 == 1);


  if (false && isDaytime())
    LEDS.setBrightness(255);
  else
    switch (currState) {
      case   Bored:
      case Violated:
        LEDS.setBrightness(BRIGHTNESS_BORED);
        break;
      default :
        LEDS.setBrightness(BRIGHTNESS_NORMAL);
        break;
    }

  //LEDS.setBrightness(BRIGHTNESS_NORMAL);
  if (nextUpdate < now) {
    unsigned long millisToChange =  updateAnimation(now);

    myprintf( "sheepSlaveBrain  sheep %d, state %d:%d, %d/%d, %d:%02d:%02d\n",
              commData.sheepNum,
              currState, commData.activated, month(), day(), hour(), minute(), second());
    int minutesSinceLastMessage = timeSinceLastMessage() / 1000 / 60;
    if (!receivedMsg)
      Serial.println(" Have not received any messages");
    else
      myprintf(" Received %d activity messages, last %d minutes ago\n",
               activityReports, minutesSinceLastMessage);

    if (!receivedMsg || minutesSinceLastMessage > 5)
      commData.activated = Active;
    myprintf(" currentEpoc %d, %dms to next epoc", animationEPOC,
             millisToChange);
    Serial.print("  animation: ");
    currentAnimation->printName();
    myprintf(" touched %02x, quality head = %d, quality back = %d\n",
             commData.currTouched, commData.headTouchQuality, commData.backTouchQuality);
    nextUpdate = now + 5000;
  }

  LEDS.clear();
  setLEDsToBlack();

  if (false) Serial.println("updating animation");
  if (!receivedMsg || commData.activated != Off) {
    if (commData.activated == Active)
      currentAnimation->update(now);
    overlays(receivedMsg);

#ifndef STANDARD_SHEEP
    if (true) {
      getSheepLEDFor(HALF_GRID_WIDTH, 0) =  CRGB::LightGrey;
      getSheepLEDFor(HALF_GRID_WIDTH, 8) =  CRGB::LightGrey;
      getSheepLEDFor(HALF_GRID_WIDTH, 9) =  CRGB::LightGrey;
      getSheepLEDFor(HALF_GRID_WIDTH, 16) =  CRGB::LightGrey;
      getSheepLEDFor(HALF_GRID_WIDTH, 17) =  CRGB::LightGrey;
      getSheepLEDFor(HALF_GRID_WIDTH, 18) =  CRGB::LightGrey;
    }
#endif
    copyLEDs();
    LEDS.show();

    unsigned long timeUsed = millis() - now;

    long timeToWait = 33 - timeUsed;
    if (timeToWait > 0)
      delay(timeToWait);
  } else {
    Serial.println("LEDs off");
    copyLEDs();
    LEDS.show();
    for (int i = 0; i < 20; i++) {
      digitalWrite(led, HIGH);   // turn the LED on (HIGH is the voltage level)
      delay(200);               // wait for a second
      digitalWrite(led, LOW);    // turn the LED off by making the voltage LOW
      delay(200);
    }
  }


}

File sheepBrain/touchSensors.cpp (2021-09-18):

#include <Arduino.h>

#include "touchSensors.h"
#include "logging.h"
#include "state.h"
#include "scheduler.h"
#include "sound.h"
#include "comm.h"
#include "state.h"

#include "util.h"

Adafruit_MPR121 cap = Adafruit_MPR121();

uint16_t STABLE_VALUE = 0;
const bool AUTO_CONFIGURE = true;
uint8_t  sensorToPlot  = numTouchSensors;

#define _BV(bit)   (1 << ((uint8_t)bit))

#include "printf.h"

boolean debugTouch = false;

boolean plotTouch = false;

uint16_t minRecentValue[numTouchSensors];
uint16_t maxRecentValue[numTouchSensors];
uint16_t stableValue[numTouchSensors];
uint16_t currentValue[numTouchSensors];
uint16_t filteredValue[numTouchSensors];
unsigned long lastResetOf[numTouchSensors];


const int HISTOGRAM_SCALE = 2;
const int HISTOGRAM_SIZE = 1024 / HISTOGRAM_SCALE;

uint16_t histogram[numTouchSensors][HISTOGRAM_SIZE];
uint16_t histogramCount[numTouchSensors];

uint16_t currTouched;
const int RING_BUFFER_SIZE = 4;

int16_t ringBuffer[numTouchSensors][RING_BUFFER_SIZE];
uint8_t ringBufferPos = 0;

uint8_t ringBufferFill = 0;

uint16_t numSamples = 0;
const boolean DISABLE_TOUCH_DURING_SOUND = false;

const uint32_t oneMinute = 60*1000;
const uint16_t resetSensorsInterval = 15000;
unsigned long nextSensorResetInterval = 0;

unsigned long lastTouch[numTouchSensors];
unsigned long lastUntouch[numTouchSensors];
unsigned long lastTouchStarted[numTouchSensors];
unsigned long lastUntouchedStarted[numTouchSensors];
unsigned long lastDisabled;

boolean valid[numTouchSensors];

const uint8_t  FFI = 3;
const uint8_t  SFI = 3;
const uint8_t  ESI = 0;
const uint8_t  CDC = 43; // 54;
const uint8_t  CDT = 6;

boolean fixed = false;

const boolean trace = false;
boolean wasDisabled = true;
boolean inReboot = false;
unsigned long startedReboot;
extern void turnOnTouch();

extern void turnOffTouch();

boolean touchDisabled() {
  return millis() < 4000 || inReboot;
}

boolean isTouched(enum TouchSensor sensor) {
  return (currTouched & _BV(sensor)) != 0;
}


uint16_t stableV(int i) {
  if (false && STABLE_VALUE != 0)
    return STABLE_VALUE;
  return stableValue[i];
}

uint8_t swapLeftRightSensors(uint8_t touched) {
  boolean leftTouched = (touched & _BV(LEFT_SENSOR)) != 0;
  boolean rightTouched = (touched & _BV(RIGHT_SENSOR)) != 0;
  touched = touched & 0xf3;
  if (leftTouched)
    touched |= _BV(RIGHT_SENSOR);
  if (rightTouched)
    touched |= _BV(LEFT_SENSOR);
  return touched;
}

uint8_t CDTx_value(uint8_t addr) {
  addr += offsetToFirstSensor;
  uint8_t value = cap.readRegister8(0x6C + addr / 2);
  if (addr % 2 == 0)
    return value & 0x07;
  return (value >> 4) & 0x07;
}

uint8_t CDTx_value(enum TouchSensor sensor) {
  return CDTx_value((uint8_t) sensor);
}

uint8_t CDCx_value(uint8_t sensor) {
  return cap.readRegister8(0x5f + offsetToFirstSensor + sensor) & 0x3f;
}
uint8_t CDCx_value(enum TouchSensor sensor) {
  return CDCx_value((uint8_t) sensor);

}

void checkValid() {
  for (int t = 0; t < numTouchSensors; t++)
    valid[t] = true;  // CDTx_value(t) > 2;
}

bool isActive() {
  if (millis() < 30 * oneMinute) 
    return true;
  if ( untouchDuration() < 15 * oneMinute) 
    return true;
  return false;
}
void setupTouch() {
  Serial.println("setting up touch");

  // Default address is 0x5A, if tied to 3.3V its 0x5B
  // If tied to SDA its 0x5C and if SCL then 0x5D
  while  (!cap.begin(0x5A)) {
    Serial.println("MPR121 not found, check wiring?");
    setupDelay(1000);
  }
  Serial.println("MPR121 found!");
  for (int t = 0; t < numTouchSensors; t++) {
    lastTouch[t] = 0;
    lastUntouch[t] = 0;
    lastTouchStarted[t] = 0;
    lastUntouchedStarted[t] = 0;
    lastResetOf[t] = 0;
    histogramCount[t] = 0;
  }
  Serial.println("Applying configuration");
  mySetup();
  setupDelay(100);
  dumpConfiguration();
  checkValid();
  for (int i = firstTouchSensor; i < numTouchSensors; i++) {
    uint16_t value = cap.filteredData(offsetToFirstSensor + i);
    if (!valid[i])
      myprintf(Serial, "sensor %d not connected\n", i);
    else if (value > 10)
      stableValue[i] = value - 1;
    myprintf(Serial, "sensor %d = %d\n", i, value);

  }
  nextSensorResetInterval = millis() + 1000;
  addScheduledActivity(50, updateTouchData, "touch");
  Serial.println("done with touch setup");
}

void dumpTouchData(int i) {
  Serial.print(i);
  Serial.print(" ");
  Serial.print(isTouched((TouchSensor)i) ? "t " : "- ");
  Serial.print(filteredValue[i]);
  Serial.print(" ");
  Serial.print(stableV(i));
  Serial.print("  ");
  Serial.print(touchDuration((TouchSensor)i));
  Serial.print("  ");
  Serial.println(untouchDuration((TouchSensor)i));
}
void dumpTouchData() {

  if (true) {
    for (int i = 0; i < 6; i++)
      dumpTouchData(i);
  } else
    for (int i = 0; i < 6; i++) {
      Serial.print(cap.filteredData(offsetToFirstSensor + i) - stableV(i));
      Serial.print("  ");
    }
  Serial.println();
}

void wasTouchedInappropriately() {


}

uint8_t touchThreshold(uint8_t i) {

  enum TouchSensor sensor = (TouchSensor) i;
  switch (sensor) {
    case HEAD_SENSOR:
      return 6;
    case LEFT_SENSOR:
    case RIGHT_SENSOR:
      return 15;
    case PRIVATES_SENSOR:
      return 20;
    case BACK_SENSOR:
    case RUMP_SENSOR:
    default:
      return 15;
  }
}

int16_t sensorValue(enum TouchSensor sensor) {
  int value = cap.filteredData(offsetToFirstSensor + (uint8_t) sensor);
  if (value < 10) return 0;
  return value - ( stableValue[sensor] - touchThreshold((uint8_t)sensor));
}

unsigned long lastReset = 20000;

boolean isStable(int sensor) {
  if (minRecentValue[sensor] < 200)
    return false;
  int range = maxRecentValue[sensor] - minRecentValue[sensor];
  int maxRange = 5;
  unsigned long secondsSinceLastReset = (millis() - lastReset) / 1000;
  if (lastReset > 5 * 60)
    maxRange *= 2;
  return range <= maxRange;
}

void resetStableValue(int sensor) {

  if (isStable(sensor) ) {
    stableValue[sensor] = minRecentValue[sensor] - 1;
  }
  else if (printInfo())
    myprintf(Serial, "Asked to reset %d, but it isn't stable\n", sensor);

}
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

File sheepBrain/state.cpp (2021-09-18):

#include "util.h"
#include "touchSensors.h"
#include "sound.h"
#include "soundFile.h"
#include "scheduler.h"
#include "state.h"
#include "printf.h"



int msToNextSoundMin = 12000;
int msToNextSoundMax = 25000;

unsigned long nextAmbientSound = 10000;
unsigned long nextBaa = 30000;

unsigned long timeEnteredCurrentState = 0;
unsigned long lastReadyToRide = 0;

unsigned long notInTheMoodUntil = 0;

BoredState boredState;
AttentiveState attentiveState;
ReadyToRideState readyToRideState;
RidingState ridingState;
NotInTheMoodState notInTheMoodState;
ViolatedState violatedState;

SheepState * currentSheepState = &boredState;


unsigned long privateTouchDisabledUntil = 0;
int privateTouchLoad = 0;
unsigned long privateTouchFade = 0;

void setupState() {
  addScheduledActivity(100, updateState, "state");
}

boolean privateSensorEnabled() {
  return privatesEnabled && millis() > privateTouchDisabledUntil;
}

int32_t untouchDurationPrivates() {
  if (privateSensorEnabled())
    return untouchDuration(PRIVATES_SENSOR);
  return 5 * 60 * 1000;
}


uint16_t secondsSinceEnteredCurrentState() {
  return (millis() - timeEnteredCurrentState) / 1000;
}
boolean maybeRiding() {

  // handle defective sensor
  if (false && touchDuration(HEAD_SENSOR) > 60 * 1000)
    return true;

  int extra = 0;
  if (touchDuration(LEFT_SENSOR) > 1550)
    extra ++;
  if (touchDuration(RIGHT_SENSOR) > 1550)
    extra ++;
  if (touchDuration(RUMP_SENSOR) > 1550)
    extra ++;
  if (touchDuration(HEAD_SENSOR) > 1550)
    extra ++;
  int32_t backDuration = touchDuration(BACK_SENSOR);

  if (false && printInfo() ) {
    myprintf(Serial, "maybe riding: %5d %d    %5d %5d %5d\n", backDuration, extra,
             touchDuration(LEFT_SENSOR) , touchDuration(RIGHT_SENSOR) , touchDuration(RUMP_SENSOR)  );
  }
  return backDuration > 8200 && extra >= 1
         ||  backDuration > 6200 && extra >= 2
         || backDuration > 50000
         || touchDuration(HEAD_SENSOR) > 30000 && backDuration > 30000;

}

boolean definitivelyRiding() {
  int extra = 0;
  if (touchDuration(LEFT_SENSOR) > 3550)
    extra ++;
  if (touchDuration(RIGHT_SENSOR) > 3550)
    extra ++;
  if (touchDuration(RUMP_SENSOR) > 3550)
    extra ++;
  return touchDuration(BACK_SENSOR) > 15200 && extra >= 2
         || touchDuration(BACK_SENSOR) > 11000 && extra == 3;

}


boolean isTouched() {
  if (millis() < 10000) return false;
  boolean result =  touchDuration(BACK_SENSOR) > 400
                    ||  touchDuration(RUMP_SENSOR) > 400  ||  touchDuration(HEAD_SENSOR) > 400;
  return result;
}

boolean qualityTouch() {
  if (millis() < 10000) return false;
  return  qualityTime(BACK_SENSOR) > 15000
          ||  qualityTime(HEAD_SENSOR) > 12000
          ||  qualityTime(BACK_SENSOR) + qualityTime(RUMP_SENSOR) / 2
          +  2 * qualityTime(HEAD_SENSOR) > 30000;
}

boolean isIgnored() {
  if (qualityTouch() || isTouched())
    return false;

  return untouchDuration(BACK_SENSOR) > 15000
         && untouchDuration(HEAD_SENSOR) > 15000
         && untouchDuration(RUMP_SENSOR) > 10000
         && untouchDuration(LEFT_SENSOR) > 10000
         && untouchDuration(RIGHT_SENSOR) > 10000
         && untouchDurationPrivates() > 10000;
}

int privateTouches = 0;
unsigned long lastPrivateTouch = 0;
void becomeViolated() {
  notInTheMoodUntil = max(notInTheMoodUntil, millis() + 1000 * (30 + random(30, 60) + random(20, 100)));
}

boolean wouldInterrupt() {
  unsigned long now = millis();

  if (now - lastSoundStarted < 30000)
    return false; // last started more than 30 seconds ago.

  if (musicPlayer.playingMusic)
    return true;

  if (now - lastSoundPlaying < 5000)
    return true;  // been silent for less than 5 seconds

  return false;
}

unsigned long next_sheep_switch = minutesPerSheep * 60 * 1000L;

uint16_t secondsInState(SheepState & state) {
  if (currentSheepState == &state) {
    return (millis() - timeEnteredCurrentState + state.timeInState) / 1000;

  }
  return state.timeInState / 1000;
}
void logState() {
  myprintf(logFile, "X, %d, %d, %d, %d\n",
           boredState.timeStateStarted, secondsInState(boredState),
           attentiveState.timeStateStarted, secondsInState(attentiveState));
  boredState.timeStateStarted = 0;
  boredState.timeInState = 0;
  attentiveState.timeStateStarted = 0;
  attentiveState.timeStateStarted = 0;
}
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

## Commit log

2018-04-29 Add ESP32 documentation
2018-04-30 added documentation links for ESP32 & install tips
2018-04-30 Added table of I2c/Serial to main readme
    and other docs too
2018-05-27 Add example that plots filtered capacitive touch data
2018-07-01 Added laser design files
2018-07-02 Add code to compute petting on any sensor
2018-07-02 First version of led controller
2018-07-10 First round of updates for phase 2
    Add watch dog timer
    Add abstractions for collections of sound files.
    rename printf to myprintf to avoid any conflicts.
    [all.h, sheepBrain.ino, sheepSlaveBrain.ino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]
2018-07-12 Add circuit diagram
    [sheepBrainCircuit.fzz]
2018-07-20 Fritzing diagram for circuit
    [sheepBrainCircuit.fzz]
2018-07-20 Update LED controller
2018-07-25 Add shutdown for amplifier
    [sheepBrainCircuit.fzz]
2018-07-25 If x or y is out of bound, return reference to unused LED
2018-07-26 Move to i2c_t3 library
2018-07-26 Add code to dynamically adjust touch sensors whenever all sensors are stable for 30 seconds
2018-07-26 Compute battery charge & other minor changes
2018-07-26 Keep track of time of last gps update
2018-07-26 Adjust amount of debugging information from touch sensors
2018-07-27 change SHDN_MAX9744 pin to 10
2018-07-27 Don't turn volume to 0 & disable rebooting of amplifier
    [sheepBrain.ino]
2018-08-12 Remove accelerometer code
2018-08-13 Move commented code to correct place
    [comm.cpp]
2018-08-20 Working with new state framework
2018-08-20 Don't use interrupts for VS1053
2018-08-28 Always set all LEDs to black; clearing the LEDs doesn't do that.
    [sheepSlaveBrain.ino]
2018-09-17 Don't pass millis as now parameter
2018-09-22 Updates; recording current activity
2018-09-29 tuning of reboot and other code
    [all.h, animations.cpp, comm.cpp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]
2018-09-29 Disable private sensors
2018-12-02 Add circuit diagram updates
    [sheepBrainCircuit.fzz, sheepBrainCircuitNoBattery.fzz, sheepBrainCircuitPortion.fzz]
2018-12-10 Fixed a couple of bugs; passes initial tests
    [sound.cpp, state.cpp, touchSensors.cpp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]
2020-12-30 Laser designs
2021-06-20 Add RTC sample code
2021-06-28 check for printInfo() before printing
2021-06-28 Allow touch debuging of specific sensor
